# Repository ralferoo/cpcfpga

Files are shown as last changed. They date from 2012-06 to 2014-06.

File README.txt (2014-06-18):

PLEASE NOTE THAT THIS IS ONLY A PARTIAL REPOSITORY DUMP WHILE I TRY TO
SEPARATE PUBLIC AND PRIVATE PARTS...

-------------------------------------------------------------------------------

Contents
--------

This is the CPC FPGA project - a modern reimplementation of the Amstrad CPC
on an FPGA.

Whilst it's designed for use with the Amstrad CPC, the board could be
used for almost any 8-bit system. Alternatively, it could be used as a
cheap FPGA development board that includes a SCART socket, RAM, flash ROM,
PS/2 keyboard, twin joystick ports, tape input, etc...

The project is structured in these subdirectories:

bitstreams	Contains FPGA images that can be loaded from SD card
client		Contains Linux utilities to communicate with the board
datasheets	Miscellaneous datasheets (obtained publically, but are NOT
		part of this project)
docs		Various snippets of documentation I've written at various times
hardware/case	The case for revision 2 of CPC FPGA, for laser cutter use
hardware/eagle	The eagle schematic and circuit design for:
			homeboard30  (revision 1)
			homeboard99r (revision 2)
hardware/spice	Various spice analysis snippets
library/hdl	VHDL files that can be used in projects hosted on CPC FPGA
projects	Contains FPGA projects to be run on the CPC FPGA.
sidecar2	The firmware for the CPC FPGA suport chip
stuff		Old bits and bobs, to be deleted
Makefile	Used to build the system
README.txt	This file

-------------------------------------------------------------------------------

Building the CPC FPGA project
-----------------------------

The user part of CPC FPGA program can be built simply by running "make".

Other build targets:

all		Rebuild client and bitstreams
clean		Clean all build files, excluding final targets
bitstreams	Rebuild all the FPGA bitstream files

scan		Check to see if the CPC FPGA board is present
log		Keep an eye on the diagnostic log from the CPC FPGA board
dump		Dump the CPC FPGA image stored in the PROM
reload		Reload the CPC FPGA image stored in the PROM
xxx.load	Reload the CPC FPGA image for project xxx
xxx.program	Programs the CPC FPGA's PROM with the image for project xxx

sidecar2	Rebuild just the firmware
dfu		Install the firmware
reset		Resets the firmware

-------------------------------------------------------------------------------

LICENCES

The Atmega source code uses the LUFA library, licensed under the MIT library.
Please see licence/LUFA-License.txt for copyright information.

The schematic and board layout are currently licensed under the Creative
Commons Attribution-Share Alike 3.0.
Please see http://creativecommons.org/licenses/by-sa/3.0/ for more information.

If you make derivative works, you must license under a compatible licence
and include the following text:
Portions of this project are derived from CPC FPGA, (c) 2011-2013 Ranulf Doswell

Other than including the above attribution, you should rename the derivative
work so that it cannot be confused with the original CPC FPGA project, nor
can you refer to CPC FPGA in a manner that suggests the derivative work is
endorsed by CPC FGPA or used by CPC FPGA.

Any VHDL code is currently not open sourced unless explicitly mentioned.
The scope of the project is solely the hardware design and software for the
support chip.

If you need a commercial licence for the hardware portion of this project,
please contact licensing@ranulf.net for more information.

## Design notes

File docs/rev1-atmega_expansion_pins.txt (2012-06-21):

name		wire colour	raspberry pi pin

TDO_PROM	WHITE		GPIO 18 (IN) [seem to have broken 22]
TMS		GREY		GPIO 21
TCK		PURPLE		GPIO 17
TDI_FPGA	BLUE		GPIO 4

fpga	atmel	header left	header right	atmel

	PD7	EMER_BOOT	AT_RESET
		VCC		VCC
		GND		GND
	PB7	TDI_FPGA	TDO_EXP		PC6
	PB5	TCK		TDO_PROM	PB6
P87		HDR_SPARE	TMS		PB4
P86		HDR_SEL		SPI_SEL		PB0
P85		HDR_MISO	SPI_MISO	PB3
P84		HDR_SCLK	SPI_SCLK	PB1
P83		HDR_MOSI	SPI_MOSI	PB2

P99	PC4
P125	PC5
P124	PC7 / CLK0
P97	PD0
P96	PD1
P95	PD2	RXD
P93	PD3	TXD
P92	PD4
P90	PD5
89	PD6	RTS

oops, CTS should have been exposed to FPGA too

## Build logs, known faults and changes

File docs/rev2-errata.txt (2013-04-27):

Atmega PC7 is connected to TDI, would be more useful as CLKO

KEYCOL4..KEYCOL7 don't have pull-ups
JOY1_{FIRE,LEFT,RIGHT,SPARE} has double pull-ups

HDMI SCL,SDA,CEC don't have pull-ups
TFP410PAP SCL,SDA don't have pull-ups

PS/2 level conversion still has 2 different implementations, one works with
the squishy keyboards only, the other with the clicky keyboards only. WHY?

HDMI connector holes should be through plated so they can be soldered downm

Mini USB locator pins are too close

VCC and GND traces are only 0.4mm, next revision make these at least 0.6mm

TAPE_IN should have pull up resistors
arguably all the GPIO pins should too

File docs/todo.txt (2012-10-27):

Find out why some of my new flash chips don't work
Find out why some of the boards have bad RAM
Get SD card access working
Move joystick back onto 1 port, have more GPIO instead

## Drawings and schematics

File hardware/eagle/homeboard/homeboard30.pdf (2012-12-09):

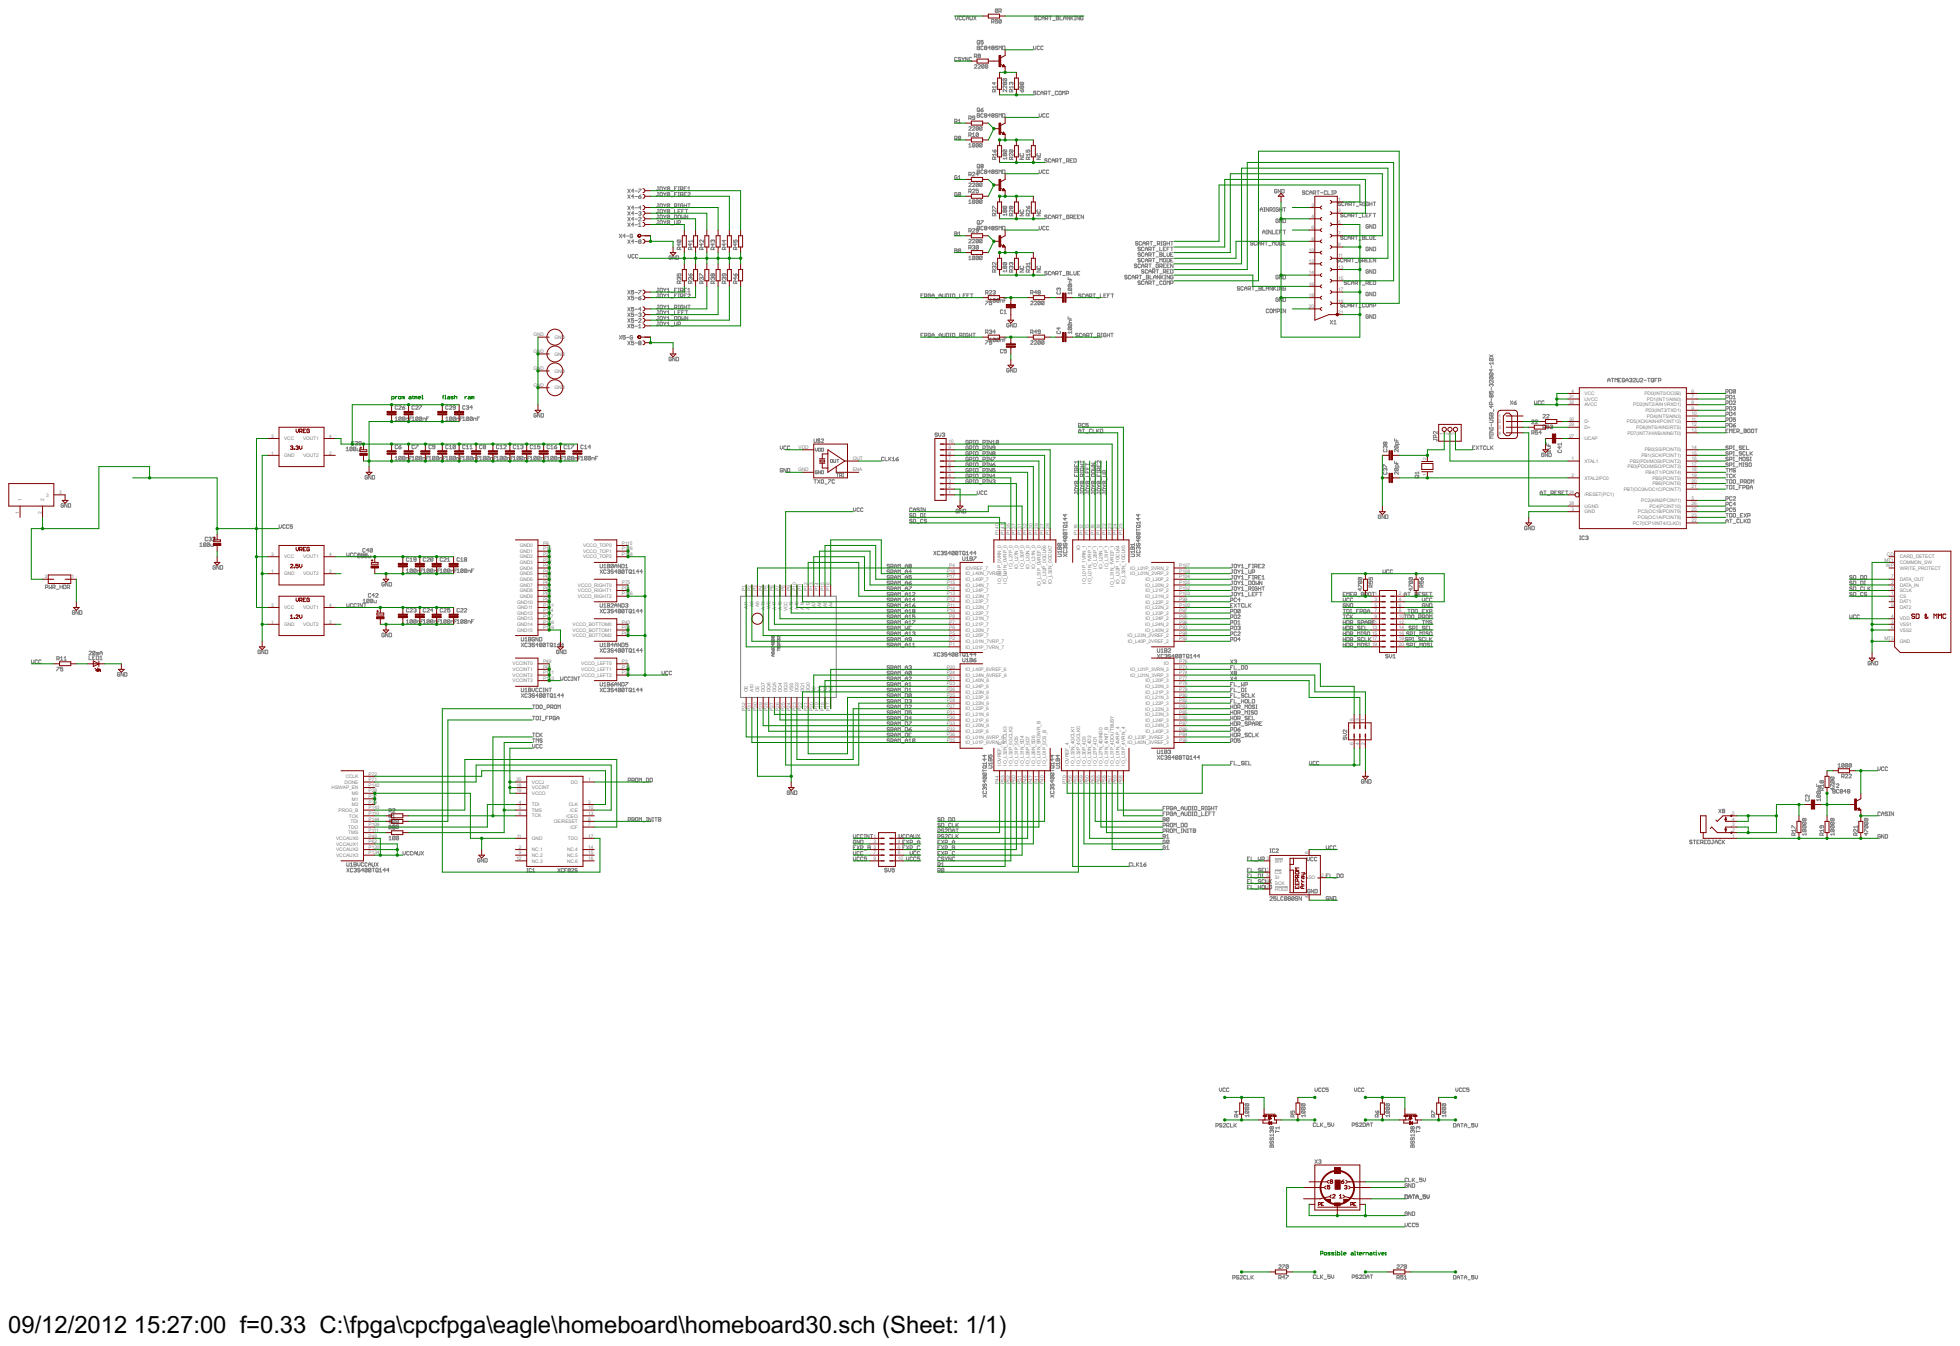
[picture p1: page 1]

09/12/2012 15:27:00 f=0.33 C:\fpga\cpcfpga\eagle\homeboard\homeboard30.sch (Sheet: 1/1)

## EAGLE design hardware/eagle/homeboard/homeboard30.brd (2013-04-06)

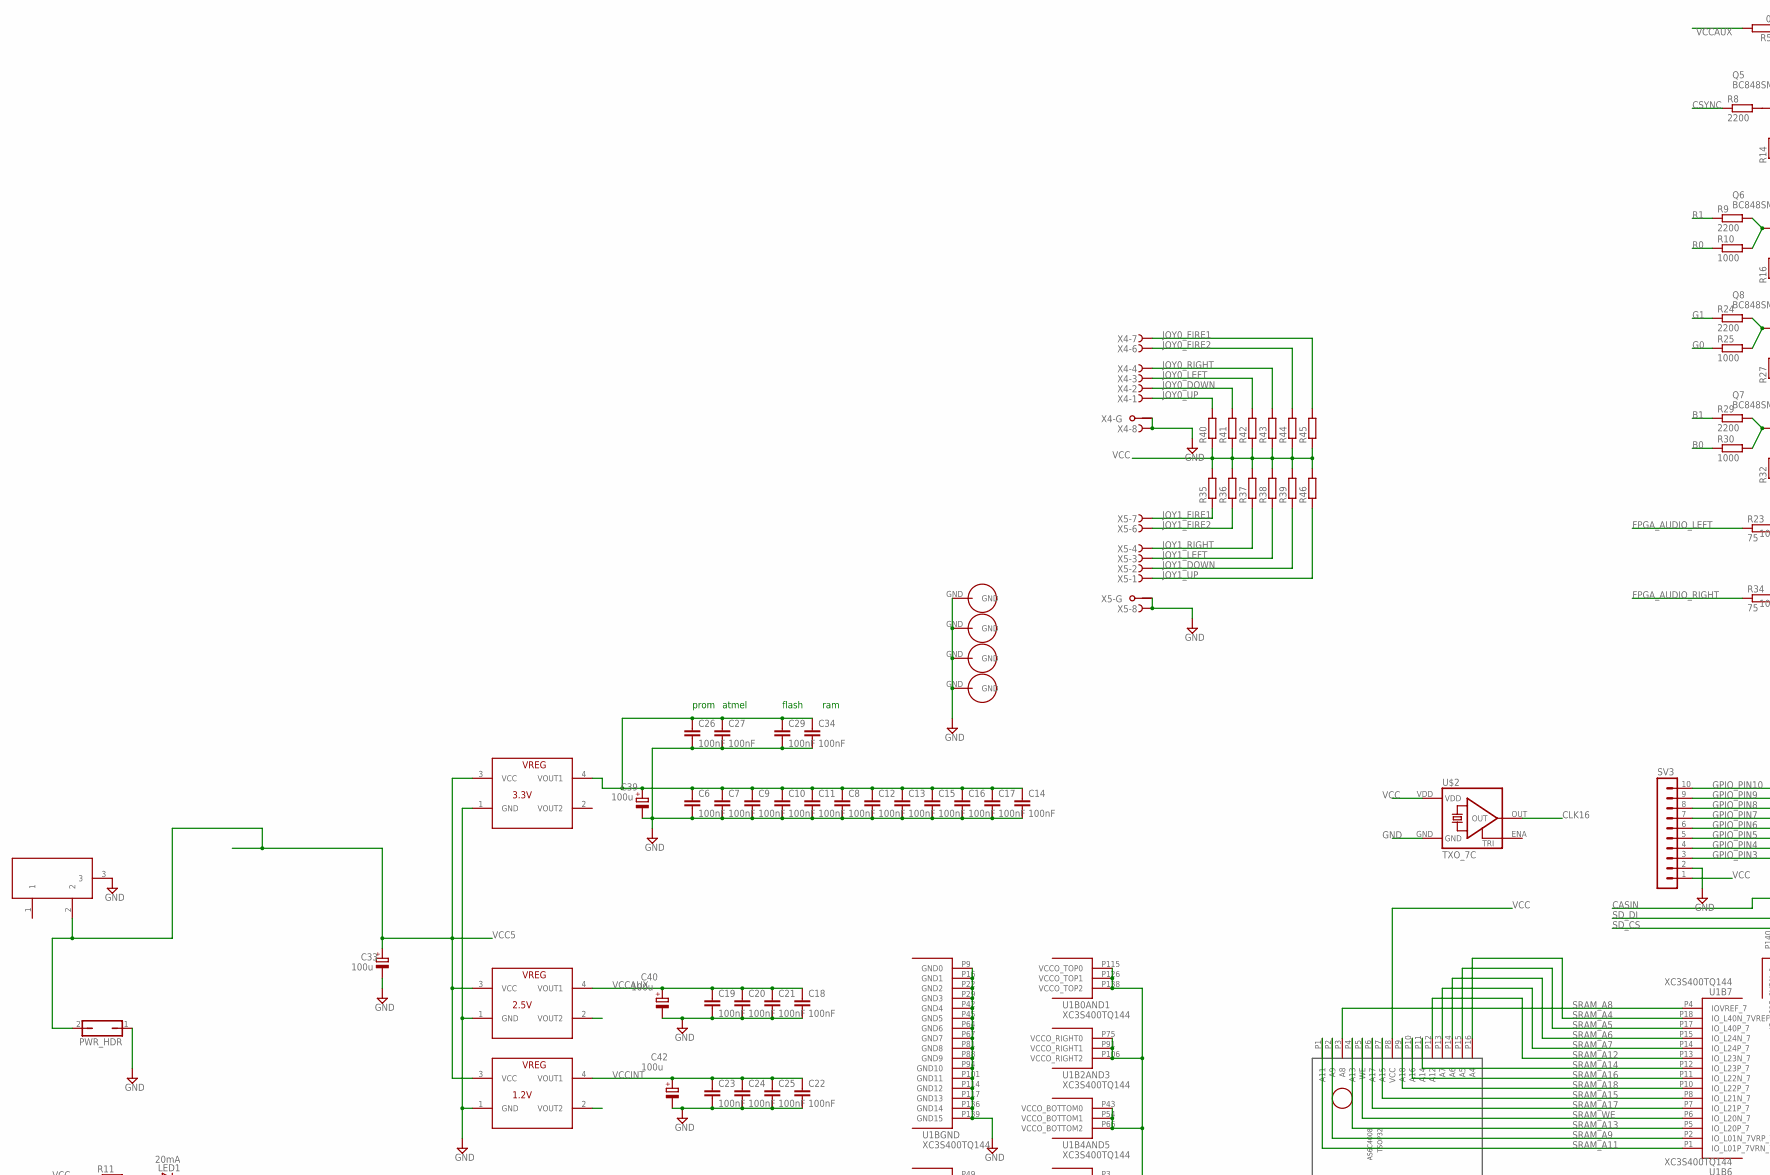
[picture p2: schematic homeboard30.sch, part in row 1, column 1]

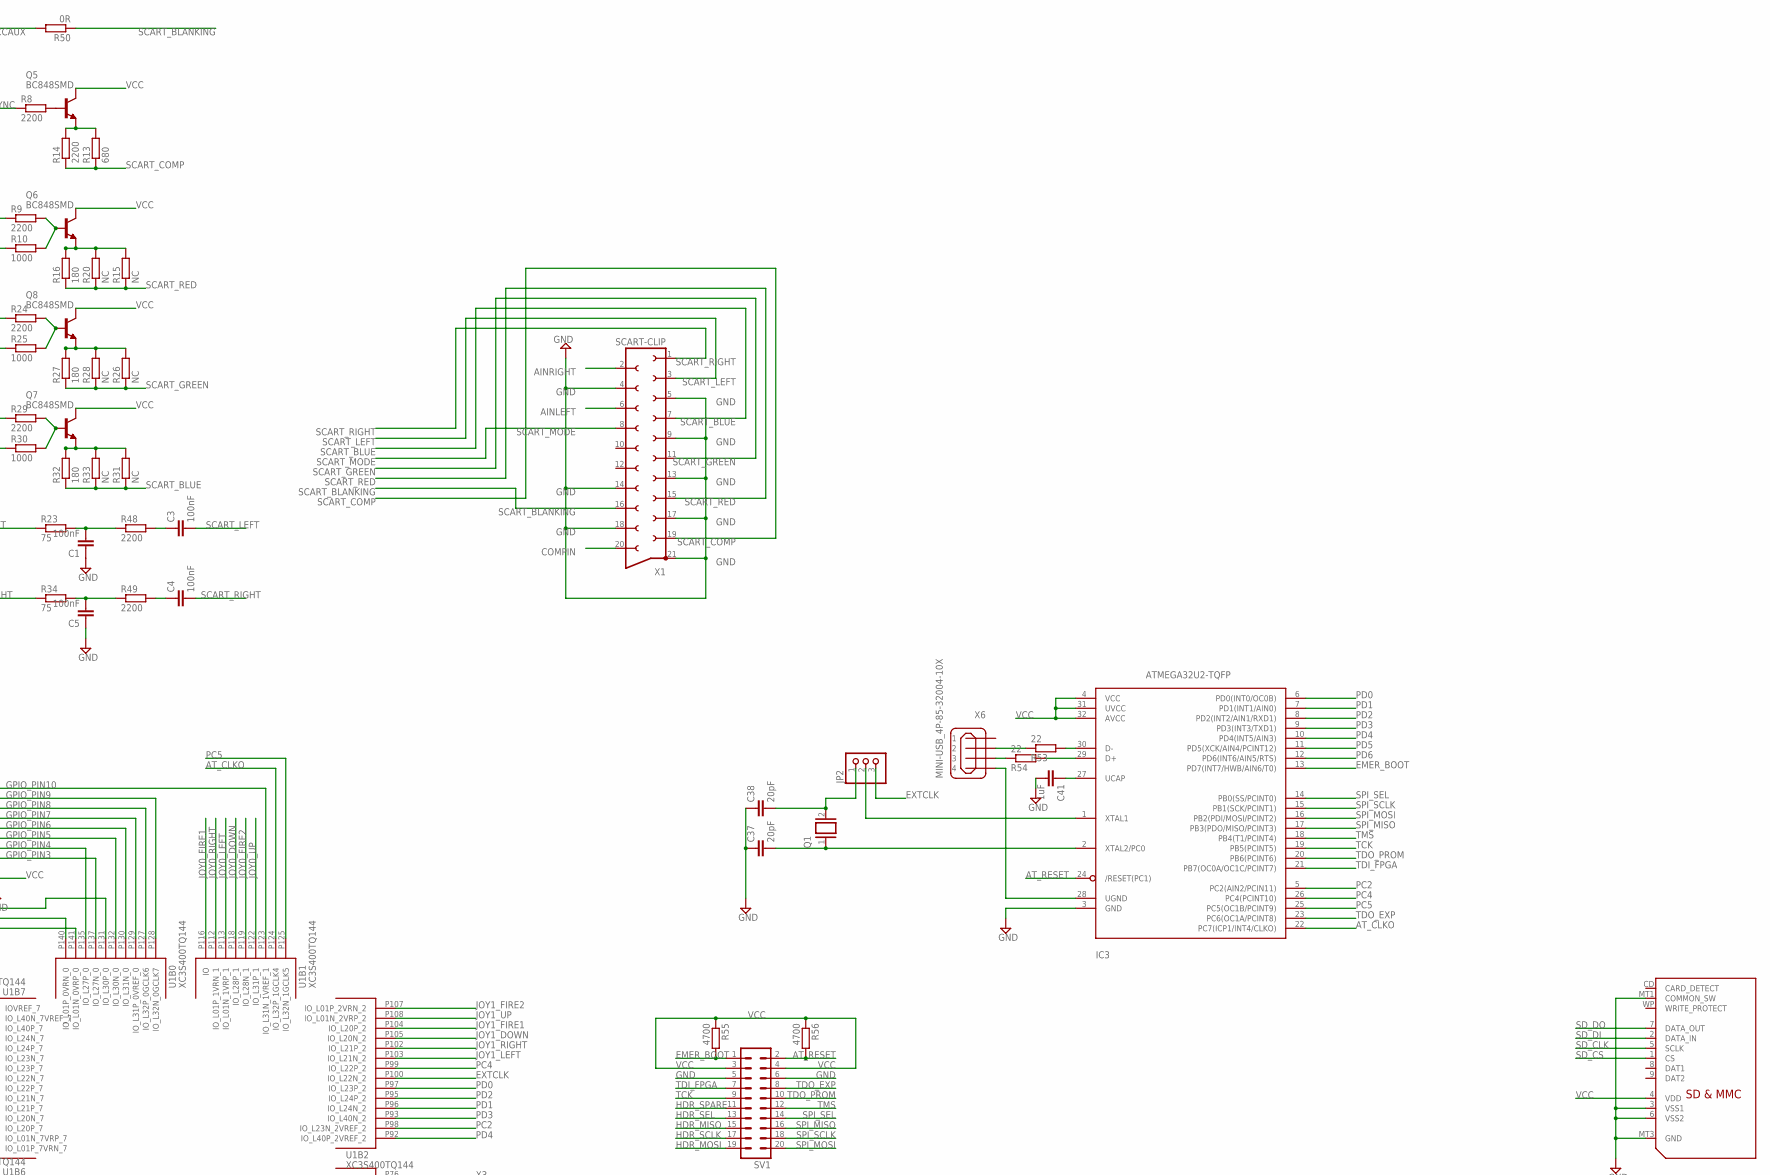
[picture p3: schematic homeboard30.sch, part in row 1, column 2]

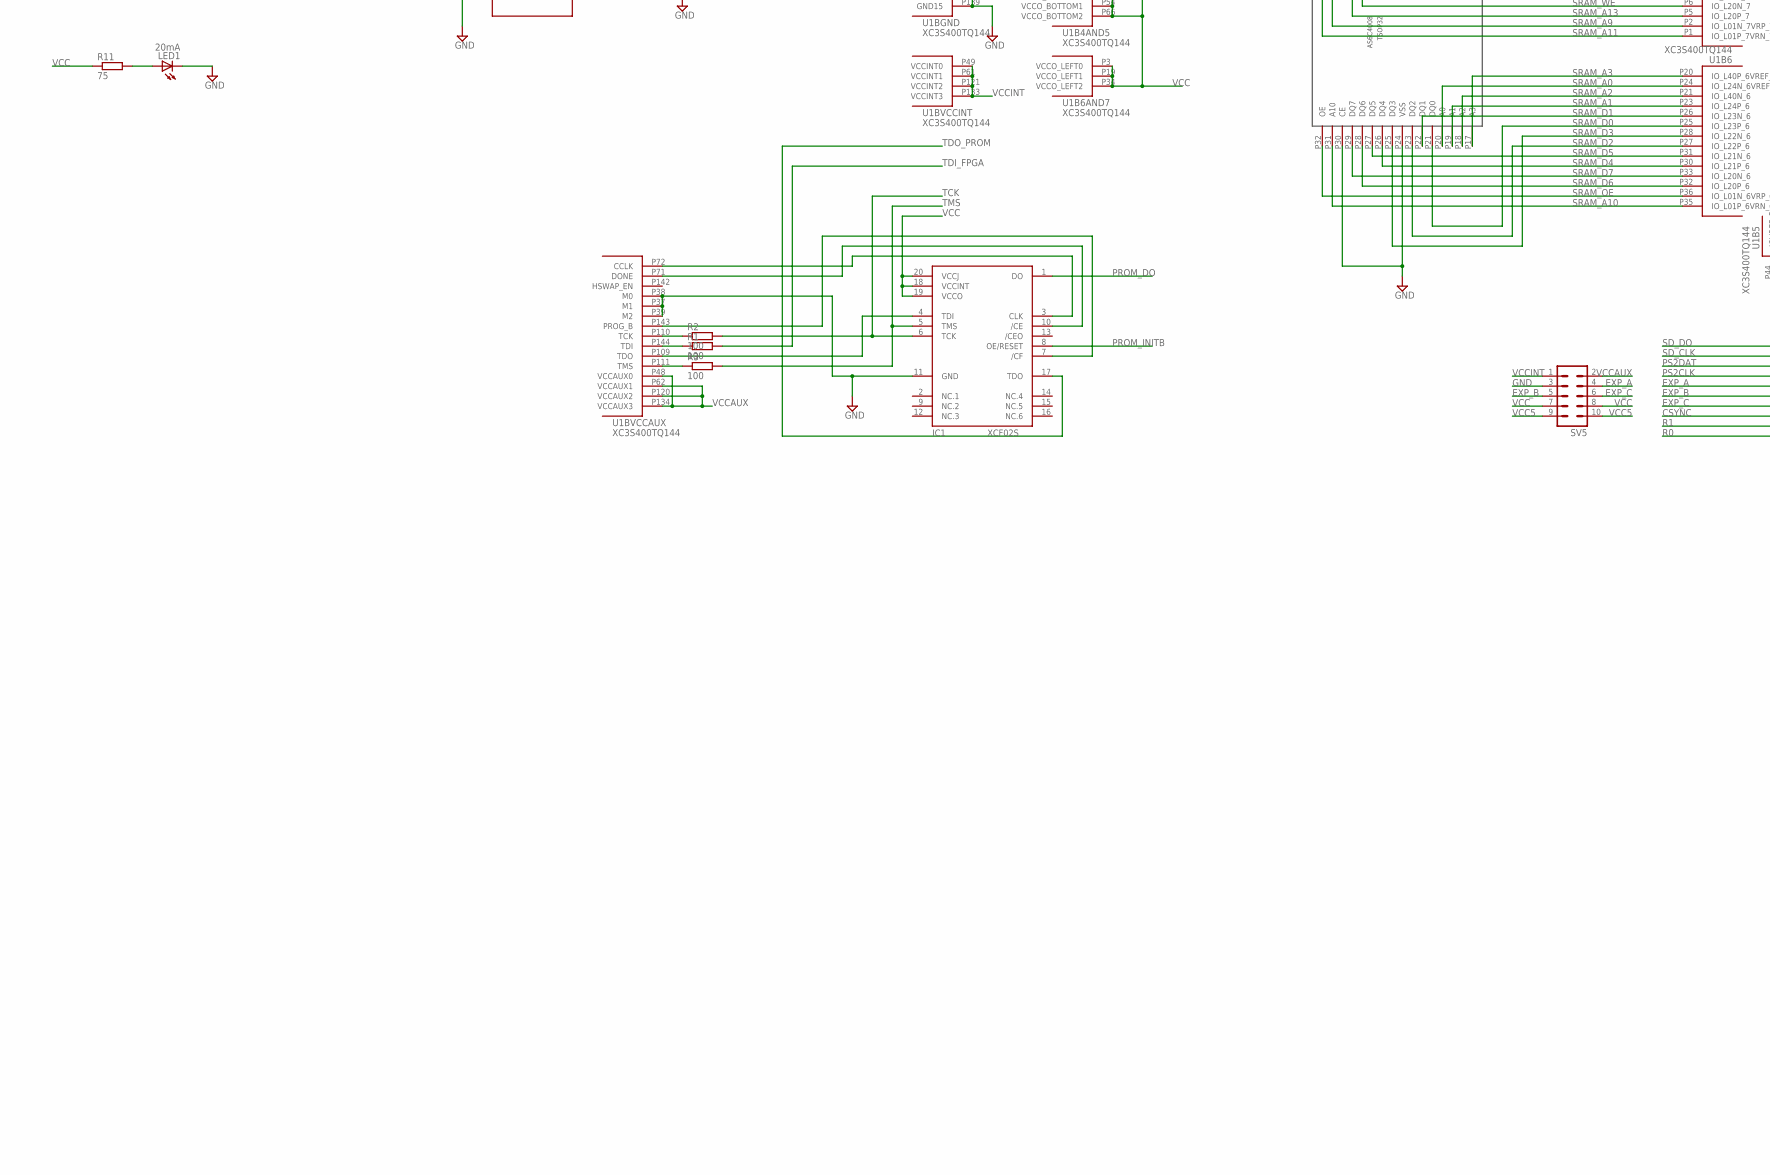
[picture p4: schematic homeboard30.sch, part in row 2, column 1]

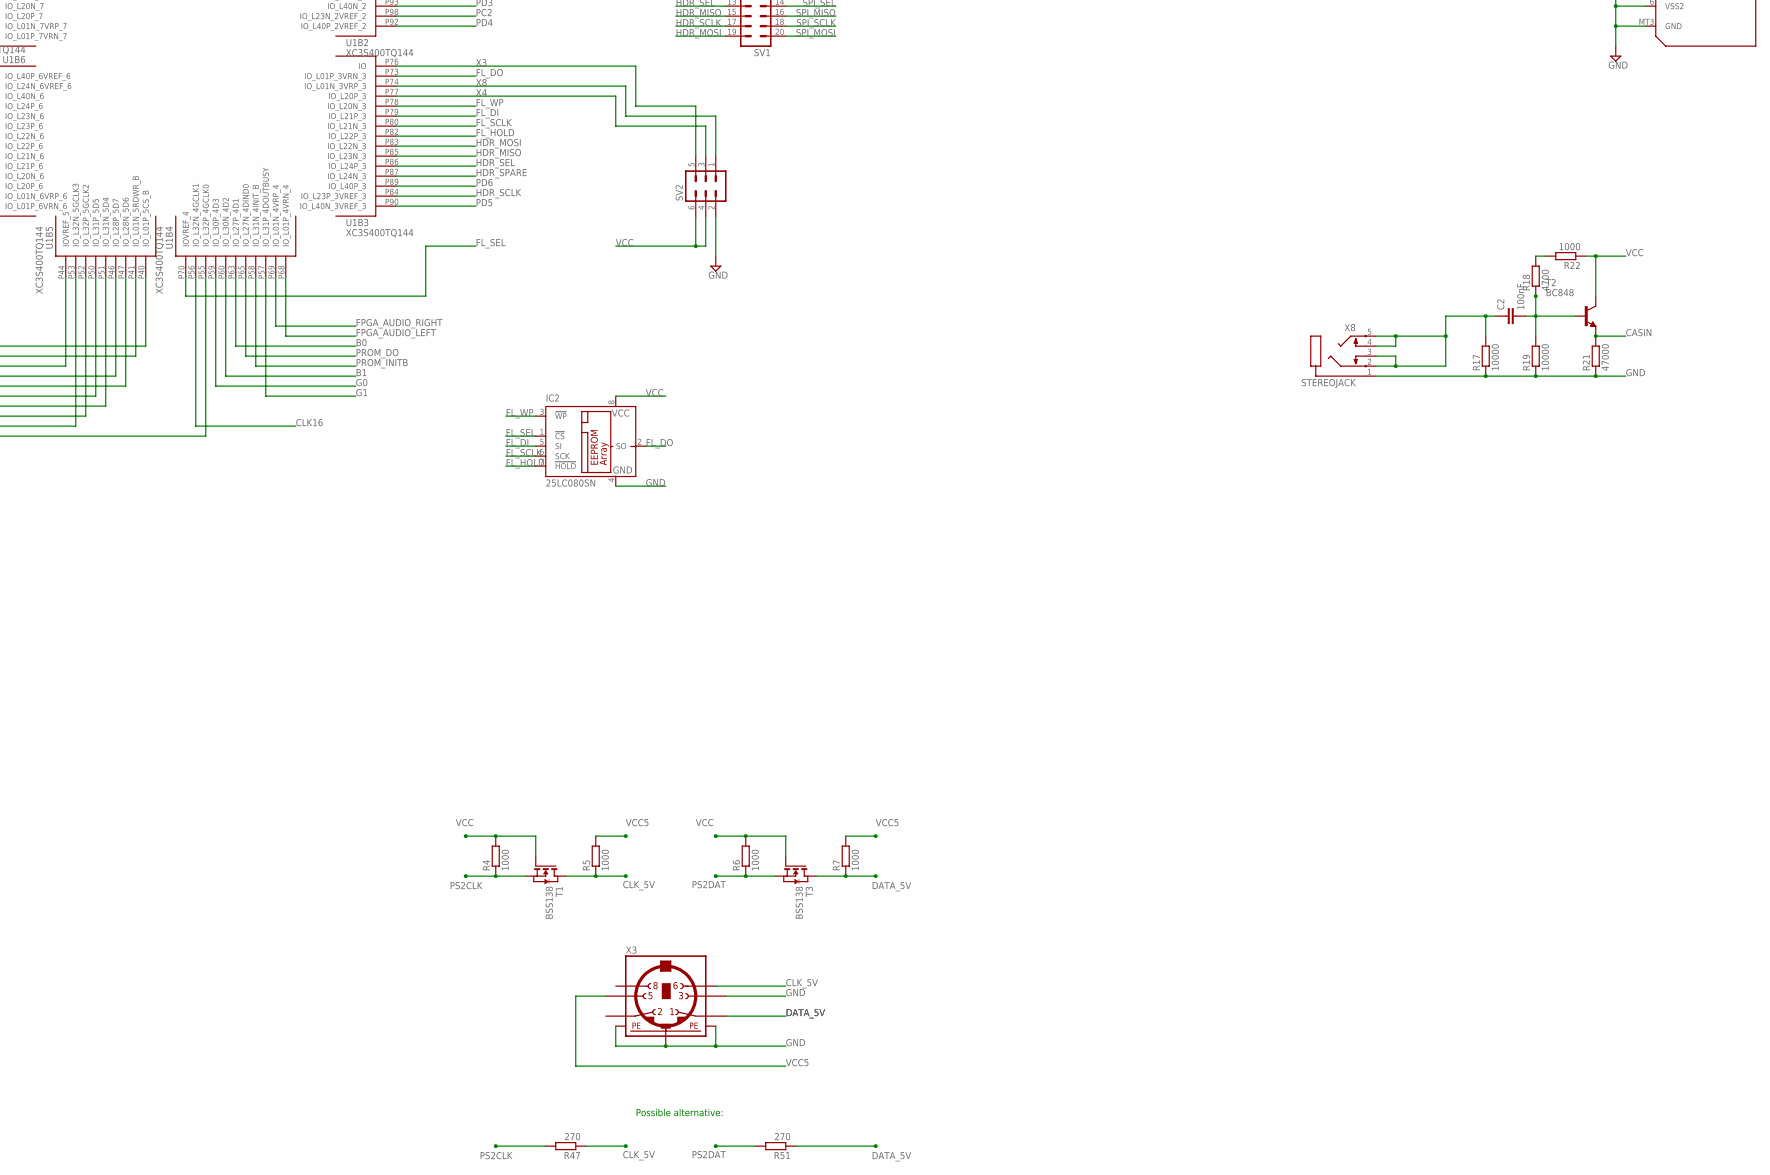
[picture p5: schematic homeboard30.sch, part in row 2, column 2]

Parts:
C1, C2, C3, C4, C5, C6, C7, C8, C9, C10, C11, C12, C13, C14, C15, C16, C17, C18, C19, C20, C21, C22, C23, C24, C25, C26, C27, C29, C34: 100nF; C0603
C33, C39, C40, C42: 100u; PANASONIC_D
C37, C38: 20pF; C0805
C41: 1uF; C0805
IC1: XCF02S; VO20
IC2: 25LC080SN; SO-08
IC3: ATMEGA32U2-TQFP; TQFP32-08
JP2: PINHD-1X3; 1X03
LED1: 20mA; CHIPLED_0805
PWR_HDR: JP1Q; JP1
Q1: XTAL/S; QS
Q5, Q6, Q7, Q8: BC848SMD; SOT23
R1, R2, R3: 100; R0805
R4, R5, R6, R7, R10, R22, R25, R30: 1000; R0805
R8, R9, R14, R24, R29: 2200; R0805
R11, R23, R34: 75; M0805
R13: 680; R0805
R15, R20, R26, R28, R31, R33: NC; R0805
R16, R27, R32: 180; R0805
R17, R19: 10000; R0805
R18, R55, R56: 4700; R0805
R21: 47000; R0805
R35, R36, R37, R38, R39, R40, R41, R42, R43, R44, R45, R46: R-EU_M0805; M0805
R47, R51: 270; R0805
R48, R49: 2200; M0805
R50: 0R; M0805
R53, R54: 22; R0805
REG1.2: 1.2V; SOT223
REG2.5: 2.5V; SOT223
REG3.3: 3.3V; SOT223
SV1: MA10-2
SV2: MA03-2
SV3: MA10-1
SV5: MA05-2
T1, T3: BSS138; SOT-23
T2: BC848; SOT23
U1: XC3S400TQ144; TQ144
U$1, U$7, U$8, U$9: GNDHOLE
U$2: TXO_7C; OSC_7C
U$3: SDMMCNOHOLE; SDCARD-NOHOLE
U$6: AS6C4008; TSOP32
X1: SCART-CLIP
X3: MINI_DIN_6; M_DIN6
X4, X5: F09HPS; F09HP
X6: MINI-USB_4P-85-32004-10X; 85-32004-10X
X7: DC21MMX; DC-21MM
X8: STEREOJACK; 20-0137

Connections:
1: X7.1
AINLEFT: X1.6
AINRIGHT: X1.2
AT_CLKO: IC3.22 (PC7(ICP1/INT4/CLKO)), U1.P124 (IO_L32P_1GCLK4)
AT_RESET: IC3.24 (/RESET(PC1)), R56.2, SV1.2
B0: R30.1, U1.P63 (IO_L27P_4D1)
B1: R29.1, U1.P60 (IO_L30N_4D2)
CASIN: R21.2, T2.2 (E), U1.P131 (IO_L30P_0)
CLK16: U1.P56 (IO_L32N_4GCLK1), U$2.OUT
CLK_5V: R5.1, R47.1, T1.1 (D), X3.6
COMPIN: X1.20
CSYNC: R8.1, U1.P52 (IO_L32P_5GCLK2)
DATA_5V: R7.1, R51.1, T3.1 (D), X3.1
EMER_BOOT: IC3.13 (PD7(INT7/HWB/AIN6/T0)), R55.2, SV1.1
EXP_A: SV5.4, U1.P47 (IO_L28N_5D6)
EXP_B: SV5.5, U1.P50 (IO_L31P_5D5)
EXP_C: SV5.6, U1.P51 (IO_L31N_5D4)
EXTCLK: JP2.3, U1.P100 (IO_L22N_2)
FL_DI: IC2.5 (SI), U1.P79 (IO_L21P_3)
FL_DO: IC2.2 (SO), U1.P73 (IO_L01P_3VRN_3)
FL_HOLD: IC2.7 (!HOLD), U1.P82 (IO_L22P_3)
FL_SCLK: IC2.6 (SCK), U1.P80 (IO_L21N_3)
FL_SEL: IC2.1 (!CS), U1.P70 (IOVREF_4)
FL_WP: IC2.3 (!WP), U1.P78 (IO_L20N_3)
FPGA_AUDIO_LEFT: R23.1, U1.P68 (IO_L01P_4VRN_4)
FPGA_AUDIO_RIGHT: R34.1, U1.P69 (IO_L01N_4VRP_4)
G0: R25.1, U1.P59 (IO_L30P_4D3)
G1: R24.1, U1.P57 (IO_L31P_4DOUTBUSY)
GND: C1.1, C5.1, C6.2, C7.2, C8.2, C9.2, C10.2, C11.2, C12.2, C13.2, C14.2, C15.2, C16.2, C17.2, C18.2, C19.2, C20.2, C21.2, C22.2, C23.2, C24.2, C25.2, C26.2, C27.2, C29.2, C33.-, C34.2, C37.1, C38.1, C39.-, C40.-, C41.2, C42.-, IC1.11 (GND), IC2.4 (GND), IC3.3 (GND), LED1.C, PWR_HDR.1, R17.1, R19.1, R21.1, REG1.2.1 (GND), REG2.5.1 (GND), REG3.3.1 (GND), SV1.5, SV1.6, SV2.2, SV3.2, SV5.3, U1.P9 (GND0), U1.P16 (GND1), U1.P22 (GND2), U1.P29 (GND3), U1.P37 (M1), U1.P38 (M0), U1.P39 (M2), U1.P42 (GND4), U1.P45 (GND5), U1.P64 (GND6), U1.P67 (GND7), U1.P81 (GND8), U1.P88 (GND9), U1.P94 (GND10), U1.P101 (GND11), U1.P114 (GND12), U1.P117 (GND13), U1.P136 (GND14), U1.P139 (GND15), U$1.GND, U$2.GND, U$3.3 (VSS1), U$3.6 (VSS2), U$3.MT1 (COMMON_SW), U$3.MT3 (GND), U$6.P24 (VSS), U$6.P30 (CE), U$7.GND, U$8.GND, U$9.GND, X1.4, X1.5, X1.9, X1.13, X1.14, X1.17, X1.18, X1.21, X3.3, X3.SH1 (PE1), X3.SH2 (PE2), X3.SH3 (PE3), X4.8 (F), X4.G1, X5.8 (F), X5.G1, X7.3, X8.1; also elsewhere on the board
GPIO_PIN3: SV3.3, U1.P137 (IO_L27N_0)
GPIO_PIN4: SV3.4, U1.P135 (IO_L27P_0)
GPIO_PIN5: SV3.5, U1.P132 (IO_L30N_0)
GPIO_PIN6: SV3.6, U1.P130 (IO_L31N_0)
GPIO_PIN7: SV3.7, U1.P129 (IO_L31P_0VREF_0)
GPIO_PIN8: SV3.8, U1.P127 (IO_L32P_0GCLK6)
GPIO_PIN9: SV3.9, U1.P128 (IO_L32N_0GCLK7)
GPIO_PIN10: SV3.10, U1.P123 (IO_L31N_1VREF_1)
HDR_MISO: SV1.15, U1.P85 (IO_L23N_3)
HDR_MOSI: SV1.19, U1.P83 (IO_L22N_3)
HDR_SCLK: SV1.17, U1.P84 (IO_L23P_3VREF_3)
HDR_SEL: SV1.13, U1.P86 (IO_L24P_3)
HDR_SPARE: SV1.11, U1.P87 (IO_L24N_3)
JOY0_DOWN: R41.2, U1.P118 (IO_L28P_1), X4.2 (F)
JOY0_FIRE1: R45.2, U1.P116 (IO), X4.7 (F)
JOY0_FIRE2: R44.2, U1.P119 (IO_L28N_1), X4.6 (F)
JOY0_LEFT: R42.2, U1.P113 (IO_L01N_1VRP_1), X4.3 (F)
JOY0_RIGHT: R43.2, U1.P112 (IO_L01P_1VRN_1), X4.4 (F)
JOY0_UP: R40.2, U1.P122 (IO_L31P_1), X4.1 (F)
JOY1_DOWN: R39.1, U1.P105 (IO_L20N_2), X5.2 (F)
JOY1_FIRE1: R35.1, U1.P104 (IO_L20P_2), X5.7 (F)
JOY1_FIRE2: R36.1, U1.P107 (IO_L01P_2VRN_2), X5.6 (F)
JOY1_LEFT: R38.1, U1.P103 (IO_L21N_2), X5.3 (F)
JOY1_RIGHT: R37.1, U1.P102 (IO_L21P_2), X5.4 (F)
JOY1_UP: R46.1, U1.P108 (IO_L01N_2VRP_2), X5.1 (F)
unnamed: IC3.1 (XTAL1), JP2.2
unnamed: C41.1, IC3.27 (UCAP)
unnamed: LED1.A, R11.2
unnamed: C37.2, IC3.2 (XTAL2/PC0), Q1.1
unnamed: C38.2, JP2.1, Q1.2
unnamed: IC1.3 (CLK), U1.P72 (CCLK)
unnamed: R53.1, X6.2
unnamed: IC1.10 (/CE), U1.P71 (DONE)
unnamed: R2.1, U1.P110 (TCK)
unnamed: IC1.7 (/CF), U1.P143 (PROG_B)
unnamed: R1.1, U1.P144 (TDI)
unnamed: R3.1, U1.P111 (TMS)
unnamed: IC3.29 (D+), R54.2
unnamed: C1.2, R23.2, R48.1
unnamed: C3.1, R48.2
unnamed: Q6.1 (B), R9.2, R10.2
unnamed: Q6.2 (E), R15.2, R16.2, R20.2
unnamed: Q8.1 (B), R24.2, R25.2
unnamed: Q8.2 (E), R26.2, R27.2, R28.2
unnamed: Q7.1 (B), R29.2, R30.2
unnamed: Q7.2 (E), R31.2, R32.2, R33.2
unnamed: Q5.2 (E), R13.2, R14.2
unnamed 77: C2.2, R18.1, R19.2, T2.1 (B); also elsewhere on the board
unnamed: C2.1, R17.2, X8.2, X8.3, X8.4, X8.5
unnamed: R18.2, R22.2
unnamed: Q5.1 (B), R8.2
unnamed: C4.1, R49.2
unnamed: C5.2, R34.2, R49.1
unnamed: R54.1, X6.3
unnamed: IC3.30 (D-), R53.2
unnamed: IC3.28 (UGND), X6.4
PC2: IC3.5 (PC2(AIN2/PCIN11)), U1.P98 (IO_L23N_2VREF_2)
PC4: IC3.26 (PC4(PCINT10)), U1.P99 (IO_L22P_2)
PC5: IC3.25 (PC5(OC1B/PCINT9)), U1.P125 (IO_L32N_1GCLK5)
PD0: IC3.6 (PD0(INT0/OC0B)), U1.P97 (IO_L23P_2)
PD1: IC3.7 (PD1(INT1/AIN0)), U1.P96 (IO_L24N_2)
PD2: IC3.8 (PD2(INT2/AIN1/RXD1)), U1.P95 (IO_L24P_2)
PD3: IC3.9 (PD3(INT3/TXD1)), U1.P93 (IO_L40N_2)
PD4: IC3.10 (PD4(INT5/AIN3)), U1.P92 (IO_L40P_2VREF_2)
PD5: IC3.11 (PD5(XCK/AIN4/PCINT12)), U1.P90 (IO_L40N_3VREF_3)
PD6: IC3.12 (PD6(INT6/AIN5/RTS)), U1.P89 (IO_L40P_3)
PROM_DO: IC1.1 (DO), U1.P65 (IO_L27N_4DIND0)
PROM_INITB: IC1.8 (OE/RESET), U1.P58 (IO_L31N_4INIT_B)
PS2CLK: R4.1, R47.2, T1.2 (S), U1.P46 (IO_L28P_5D7)
PS2DAT: R6.1, R51.2, T3.2 (S), U1.P44 (IOVREF_5)
R0: R10.1, U1.P55 (IO_L32P_4GCLK0)
R1: R9.1, U1.P53 (IO_L32N_5GCLK3)
SCART_BLANKING: R50.1, X1.16
SCART_BLUE: R31.1, R32.1, R33.1, X1.7
SCART_COMP: R13.1, R14.1, X1.19
SCART_GREEN: R26.1, R27.1, R28.1, X1.11
SCART_LEFT: C3.2, X1.3
SCART_MODE: X1.8
SCART_RED: R15.1, R16.1, R20.1, X1.15
SCART_RIGHT: C4.2, X1.1
SD_CLK: U1.P41 (IO_L01N_5RDWR_B), U$3.5 (SCLK)
SD_CS: U1.P141 (IO_L01N_0VRP_0), U$3.1 (CS)
SD_DI: U1.P140 (IO_L01P_0VRN_0), U$3.2 (DATA_IN)
SD_DO: U1.P40 (IO_L01P_5CS_B), U$3.7 (DATA_OUT)
SPI_MISO: IC3.17 (PB3(PDO/MISO/PCINT3)), SV1.16
SPI_MOSI: IC3.16 (PB2(PDI/MOSI/PCINT2)), SV1.20
SPI_SCLK: IC3.15 (PB1(SCK/PCINT1)), SV1.18
SPI_SEL: IC3.14 (PB0(SS/PCINT0)), SV1.14
SRAM_A0: U1.P24 (IO_L24N_6VREF_6), U$6.P20 (A0)
SRAM_A1: U1.P23 (IO_L24P_6), U$6.P19 (A1)
SRAM_A2: U1.P21 (IO_L40N_6), U$6.P18 (A2)
SRAM_A3: U1.P20 (IO_L40P_6VREF_6), U$6.P17 (A3)
SRAM_A4: U1.P18 (IO_L40N_7VREF_7), U$6.P16 (A4)
SRAM_A5: U1.P17 (IO_L40P_7), U$6.P15 (A5)
SRAM_A6: U1.P15 (IO_L24N_7), U$6.P14 (A6)
SRAM_A7: U1.P14 (IO_L24P_7), U$6.P13 (A7)
SRAM_A8: U1.P4 (IOVREF_7), U$6.P3 (A8)
SRAM_A9: U1.P2 (IO_L01N_7VRP_7), U$6.P2 (A9)
SRAM_A10: U1.P35 (IO_L01P_6VRN_6), U$6.P31 (A10)
SRAM_A11: U1.P1 (IO_L01P_7VRN_7), U$6.P1 (A11)
SRAM_A12: U1.P13 (IO_L23N_7), U$6.P12 (A12)
SRAM_A13: U1.P5 (IO_L20P_7), U$6.P4 (A13)
SRAM_A14: U1.P12 (IO_L23P_7), U$6.P11 (A14)
SRAM_A15: U1.P8 (IO_L21N_7), U$6.P7 (A15)
SRAM_A16: U1.P11 (IO_L22N_7), U$6.P10 (A16)
SRAM_A17: U1.P7 (IO_L21P_7), U$6.P6 (A17)
SRAM_A18: U1.P10 (IO_L22P_7), U$6.P9 (A18)
SRAM_D0: U1.P25 (IO_L23P_6), U$6.P21 (DQ0)
SRAM_D1: U1.P26 (IO_L23N_6), U$6.P22 (DQ1)
SRAM_D2: U1.P27 (IO_L22P_6), U$6.P23 (DQ2)
SRAM_D3: U1.P28 (IO_L22N_6), U$6.P25 (DQ3)
SRAM_D4: U1.P30 (IO_L21P_6), U$6.P26 (DQ4)
SRAM_D5: U1.P31 (IO_L21N_6), U$6.P27 (DQ5)
SRAM_D6: U1.P32 (IO_L20P_6), U$6.P28 (DQ6)
SRAM_D7: U1.P33 (IO_L20N_6), U$6.P29 (DQ7)
SRAM_OE: U1.P36 (IO_L01N_6VRP_6), U$6.P32 (OE)
SRAM_WE: U1.P6 (IO_L20N_7), U$6.P5 (WE)
TCK: IC1.6 (TCK), IC3.19 (PB5(PCINT5)), R2.2, SV1.9
TDI_FPGA: IC3.21 (PB7(OC0A/OC1C/PCINT7)), R1.2, SV1.7
TDO_EXP: IC3.23 (PC6(OC1A/PCINT8)), SV1.8
TDO_FPGA: IC1.4 (TDI), U1.P109 (TDO)
TDO_PROM: IC1.17 (TDO), IC3.20 (PB6(PCINT6)), SV1.10
TMS: IC1.5 (TMS), IC3.18 (PB4(T1/PCINT4)), R3.2, SV1.12
VCC: C6.1, C7.1, C8.1, C9.1, C10.1, C11.1, C12.1, C13.1, C14.1, C15.1, C16.1, C17.1, C26.1, C27.1, C29.1, C34.1, C39.+, IC1.18 (VCCINT), IC1.19 (VCCO), IC1.20 (VCCJ), IC2.8 (VCC), IC3.4 (VCC), IC3.31 (UVCC), IC3.32 (AVCC), Q5.3 (C), Q6.3 (C), Q7.3 (C), Q8.3 (C), R4.2, R6.2, R11.1, R22.1, R35.2, R36.2, R37.2, R38.2, R39.2, R40.1, R41.1, R42.1, R43.1, R44.1, R45.1, R46.2, R55.1, R56.1, REG3.3.4 (VOUT1), SV1.3, SV1.4, SV2.4, SV2.6, SV3.1, SV5.7, SV5.8, T1.3 (G), T2.3 (C), T3.3 (G), U1.P3 (VCCO_LEFT0), U1.P19 (VCCO_LEFT1), U1.P34 (VCCO_LEFT2), U1.P43 (VCCO_BOTTOM0), U1.P54 (VCCO_BOTTOM1), U1.P66 (VCCO_BOTTOM2), U1.P75 (VCCO_RIGHT0), U1.P91 (VCCO_RIGHT1), U1.P106 (VCCO_RIGHT2), U1.P115 (VCCO_TOP0), U1.P126 (VCCO_TOP1), U1.P138 (VCCO_TOP2), U$2.VDD, U$3.4 (VDD), U$6.P8 (VCC)
VCC5: C33.+, PWR_HDR.2, R5.2, R7.2, REG1.2.3 (VCC), REG2.5.3 (VCC), REG3.3.3 (VCC), SV5.9, SV5.10, X3.5, X7.2
VCCAUX: C18.1, C19.1, C20.1, C21.1, C40.+, R50.2, REG2.5.4 (VOUT1), SV5.2, U1.P48 (VCCAUX0), U1.P62 (VCCAUX1), U1.P120 (VCCAUX2), U1.P134 (VCCAUX3)
VCCINT: C22.1, C23.1, C24.1, C25.1, C42.+, REG1.2.4 (VOUT1), SV5.1, U1.P49 (VCCINT0), U1.P61 (VCCINT1), U1.P121 (VCCINT2), U1.P133 (VCCINT3)
X3: SV2.5, U1.P76 (IO)
X4: SV2.3, U1.P77 (IO_L20P_3)
X8: SV2.1, U1.P74 (IO_L01N_3VRP_3)

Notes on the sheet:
Possible alternative:
atmel
prom
flash
ram

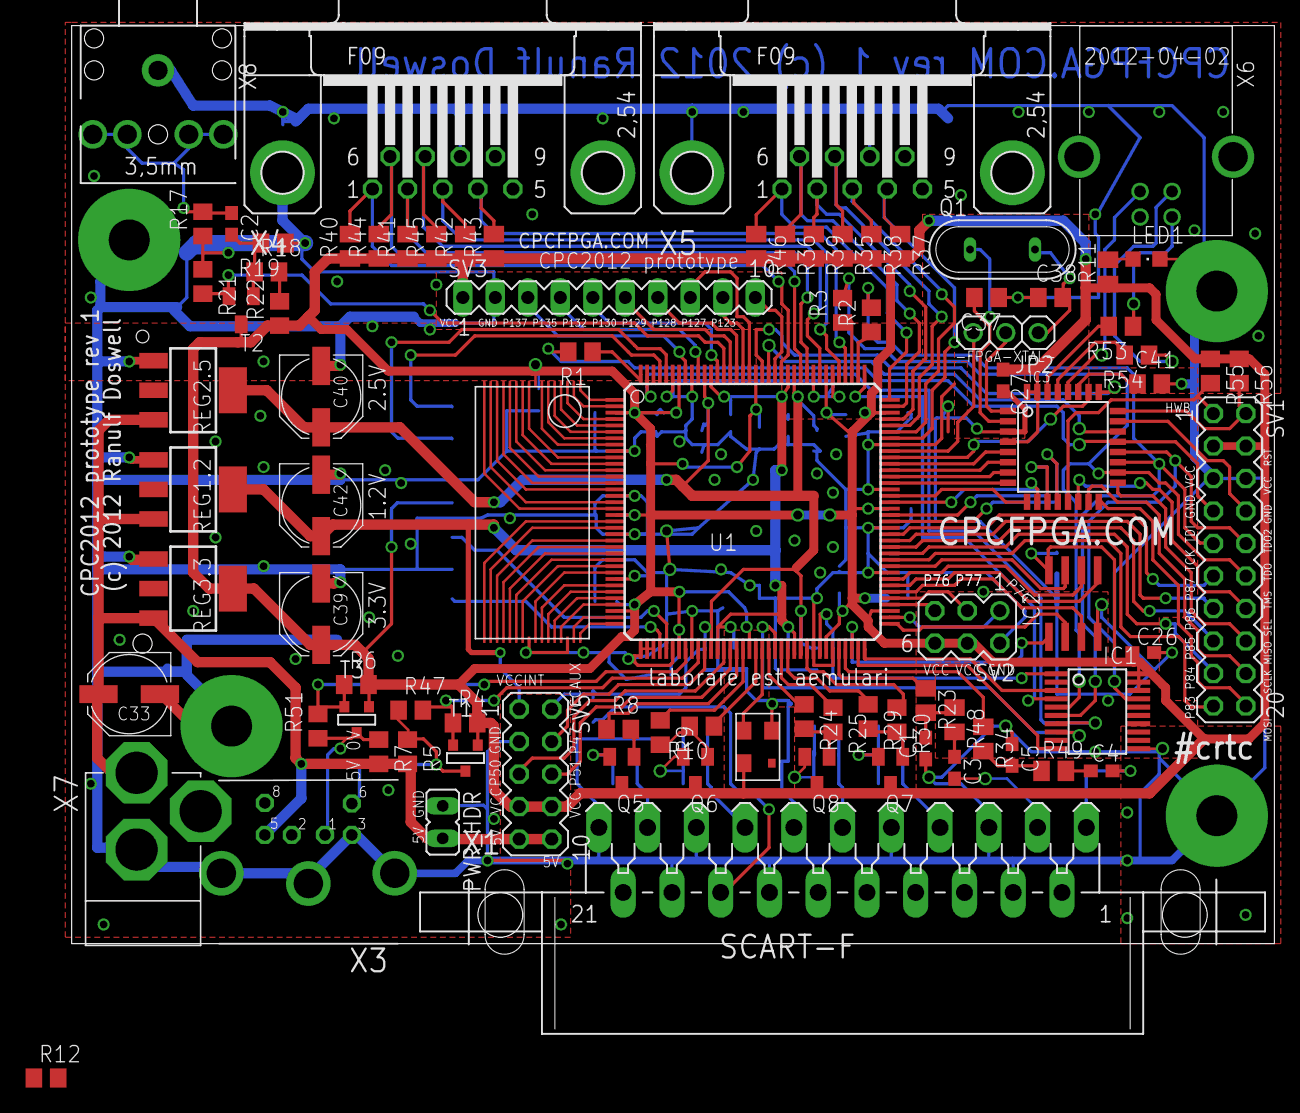
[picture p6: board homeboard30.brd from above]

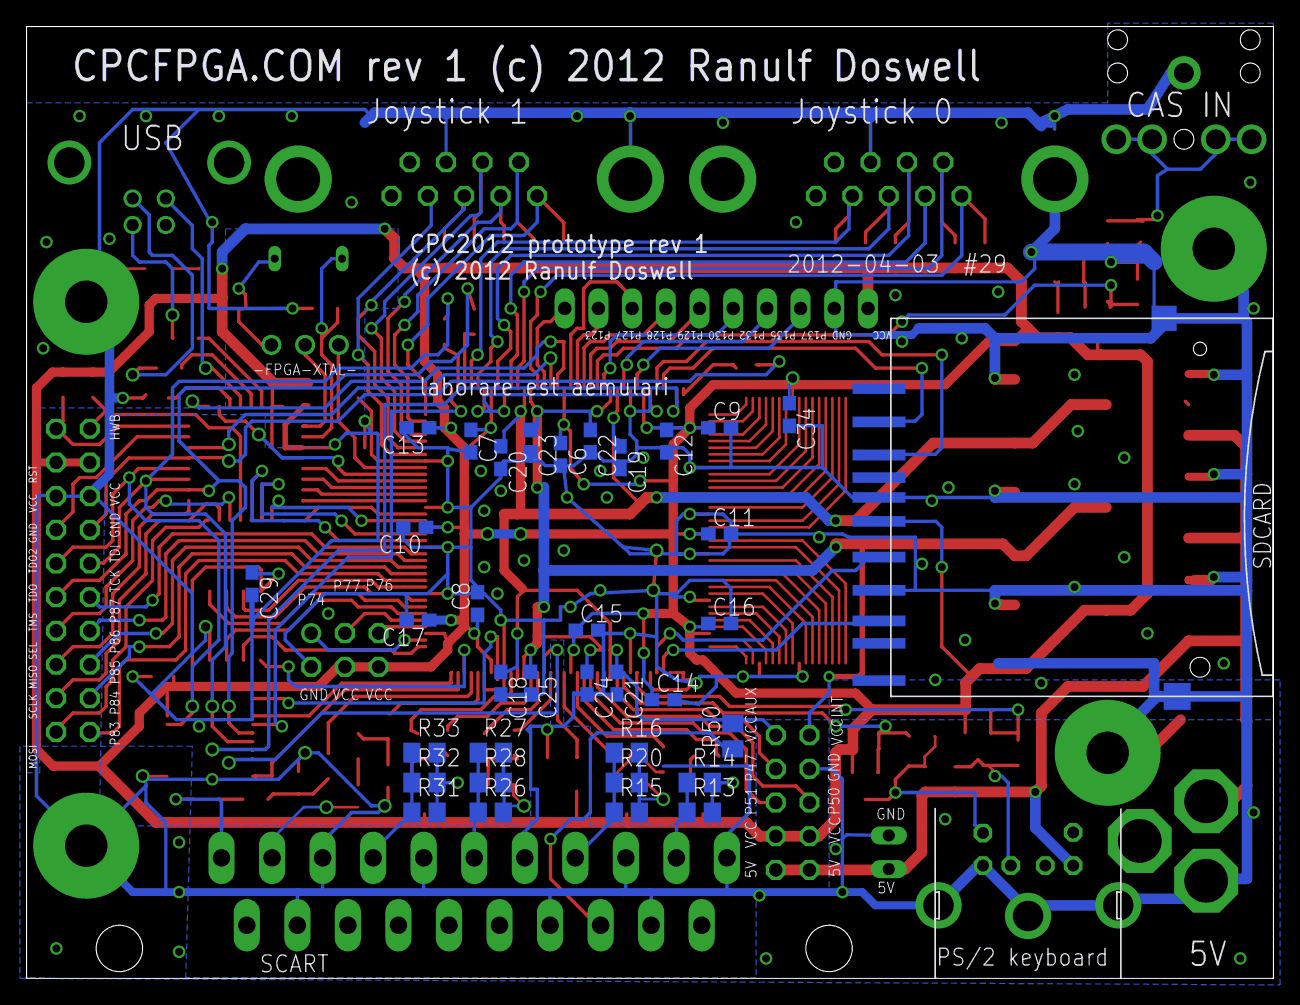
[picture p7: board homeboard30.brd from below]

Board: 2 copper layers, 94.0 x 71.8 mm, 127 parts (34 on the bottom side), 154 nets.

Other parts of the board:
R12: 47000; R0805

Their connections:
GND: R12.1; also elsewhere on the board
unnamed 77: R12.2; also elsewhere on the board

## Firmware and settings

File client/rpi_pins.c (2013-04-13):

#define DUMP_ALL_JTAG_TRAFFIC

#include <time.h>
#include <errno.h>

#include "gpio.h"

//#define GPIO_TMS 21
//#define GPIO_TCK 17
//#define GPIO_TDI 4
//#define GPIO_TDO 18 //22

#define GPIO_TMS 8
#define GPIO_TCK 25
#define GPIO_TDI 23
#define GPIO_TDO 24

#include <unistd.h>

#define BCM2708_PERI_BASE        0x20000000
#define GPIO_BASE                (BCM2708_PERI_BASE + 0x200000) /* GPIO controller */


#include <stdio.h>
#include <string.h>
#include <stdlib.h>
#include <dirent.h>
#include <fcntl.h>
#include <assert.h>
#include <sys/mman.h>
#include <sys/types.h>
#include <sys/stat.h>

#include <unistd.h>

#define PAGE_SIZE (4*1024)
#define BLOCK_SIZE (4*1024)

int  mem_fd;
char *gpio_mem, *gpio_map;
char *spi0_mem, *spi0_map;


// I/O access
volatile unsigned *gpio;


// GPIO setup macros. Always use INP_GPIO(x) before using OUT_GPIO(x) or SET_GPIO_ALT(x,y)
#define INP_GPIO(g) *(gpio+((g)/10)) &= ~(7<<(((g)%10)*3))
#define OUT_GPIO(g) *(gpio+((g)/10)) |=  (1<<(((g)%10)*3))
#define SET_GPIO_ALT(g,a) *(gpio+(((g)/10))) |= (((a)<=3?(a)+4:(a)==4?3:2)<<(((g)%10)*3))

#define GPIO_SET *(gpio+7)  // sets   bits which are 1 ignores bits which are 0
#define GPIO_CLR *(gpio+10) // clears bits which are 1 ignores bits which are 0
#define GPIO_LEV *(gpio+13) // gets levels of bits

void pinSetupIO();


#ifdef DUMP_ALL_JTAG_TRAFFIC
int dumper_fd = -1;
unsigned char dumper_buffer[10000];
int dumper_bufptr = 0;
int dumper_total = 0;
#endif

void TrafficDumpExit(void)
{
#ifdef DUMP_ALL_JTAG_TRAFFIC
	if (dumper_fd >= 0) {
//		printf("TrafficDumpExit flush\n");
		dumper_buffer[ dumper_bufptr++ ] = '\n';
		if (dumper_bufptr) {
			int wlen = write(dumper_fd, dumper_buffer, dumper_bufptr);
			if (dumper_bufptr != wlen)
				printf("Error flushing final jtag buffer wrote %d instead of %d bytes\n", wlen, dumper_bufptr);
		}
		close(dumper_fd);
		dumper_fd = -1;
		dumper_bufptr = 0;
	}
#endif
}

void TrafficDumpBit(int tms, int tdi, int tdo)
{
#ifdef DUMP_ALL_JTAG_TRAFFIC
	unsigned char out = tdi ?         '1' : '0';		//    1=TDI (from us to JTAG)
	if (tdo)		out |=    2;			//    2=TDO (from JTAG to us) 
	if (tms)		out |= 0x4;			// 0x8=TMS (JTAG transition)

	if ( (dumper_bufptr+4) > sizeof(dumper_buffer)) {
//		printf("TrafficDumpBit flush\n");
		if (dumper_fd >= 0) {
			int wlen = write(dumper_fd, dumper_buffer, dumper_bufptr);
			if (dumper_bufptr != wlen)
				printf("Error flushing jtag buffer wrote %d instead of %d bytes\n", wlen, dumper_bufptr);
		}
		dumper_bufptr = 0;
	}

	dumper_buffer[ dumper_bufptr++ ] = out;
	dumper_total++;
	if ((dumper_total&0x3f) == 0)
		dumper_buffer[ dumper_bufptr++ ] = '\n';
#endif
}

void TrafficDumpInit(void)
{
#ifdef DUMP_ALL_JTAG_TRAFFIC
	if (dumper_fd < 0) {
		char path_buffer[128];
		sprintf(path_buffer, "/jtaglogs/jtag-%ld.log", time(0) );
		dumper_fd = open(path_buffer, O_WRONLY | O_CREAT, 0777);
		dumper_bufptr = 0;
		dumper_total = 0;

		atexit(TrafficDumpExit);
	}
#endif
}


//
// Set up a memory regions to access GPIO
//
void pinSetupIO()
{

   /* open /dev/mem */
   if ((mem_fd = open("/dev/mem", O_RDWR|O_SYNC) ) < 0) {
      printf("can't open /dev/mem \n");
      exit (-1);
   }

   /* mmap GPIO */

   // Allocate MAP block
   if ((gpio_mem = malloc(BLOCK_SIZE + (PAGE_SIZE-1))) == NULL) {
      printf("allocation error \n");
      exit (-1);
   }

   // Make sure pointer is on 4K boundary
   if ((unsigned long)gpio_mem % PAGE_SIZE)
     gpio_mem += PAGE_SIZE - ((unsigned long)gpio_mem % PAGE_SIZE);

   // Now map it
   gpio_map = (unsigned char *)mmap(
      (caddr_t)gpio_mem,
      BLOCK_SIZE,
      PROT_READ|PROT_WRITE,
      MAP_SHARED|MAP_FIXED,
      mem_fd,
      GPIO_BASE
   );

   if ((long)gpio_map < 0) {
      printf("mmap error %d\n", (int)gpio_map);
      exit (-1);
   }

   // Always use volatile pointer!
   gpio = (volatile unsigned *)gpio_map;

#ifdef DUMP_ALL_JTAG_TRAFFIC
	TrafficDumpInit();
#endif


} // pinSetupIO

inline void pinSetDirectionInput(int i)
{
    INP_GPIO(i);
}

inline void pinSetDirectionOutput(int i)
{
    INP_GPIO(i); // must use INP_GPIO before we can use OUT_GPIO
    OUT_GPIO(i);
}

inline void pinOutput(int i, int v)
{
	if(v)
		GPIO_SET = 1<<i;
	else
		GPIO_CLR = 1<<i;
}

inline int pinInput(int i)
{
	return ( GPIO_LEV & (1<<i) ) ? 1 : 0;
}

///////////////////////////////////////////////////////////////////////////

void jtagInit(void)
{
	// Set up gpi pointer for direct register access
	pinSetupIO();

	// set pin directions
	pinOutput(GPIO_TMS,1);
	pinOutput(GPIO_TCK,0);
	pinSetDirectionOutput(GPIO_TMS);
	pinSetDirectionOutput(GPIO_TCK);
	pinSetDirectionOutput(GPIO_TDI);
	pinSetDirectionInput (GPIO_TDO);

	int i;
	for (i=0;i<20;i++)
		asm("nop;nop;nop;nop;nop;nop");	// 6/750 ms = 8ns
}

///////////////////////////////////////////////////////////////////////////
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

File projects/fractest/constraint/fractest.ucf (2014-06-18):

# SYSTEM
#

# this is temporary clock... broken the real one :(
#NET "CLK48"		LOC = "P53"	| IOSTANDARD = LVCMOS33;
NET "CLK_48"		LOC = "P128"	| IOSTANDARD = LVCMOS33;
NET "CLK_48" TNM_NET = "CLK_48";
TIMESPEC "TS_CLK48" = PERIOD "CLK_48" 20.833ns HIGH 50%;

###########################################################################

# Keyboard shift regs
#
NET "JOY_IN_DATA"	LOC = "P46"	| IOSTANDARD = LVCMOS33;
NET "JOY_KEY_LATCH"	LOC = "P40"	| IOSTANDARD = LVCMOS33;
NET "JOY_KEY_CLK"	LOC = "P44"	| IOSTANDARD = LVCMOS33;
NET "KEY_OUT_DATA"	LOC = "P41"	| IOSTANDARD = LVCMOS33;

###########################################################################

# SCART
#
NET "SCART_CSYNC"	LOC = "P112"	| IOSTANDARD = LVCMOS33;
NET "SCART_R[1]"	LOC = "P77"	| IOSTANDARD = LVCMOS33;
NET "SCART_R[0]"	LOC = "P73"	| IOSTANDARD = LVCMOS33;
NET "SCART_G[1]"	LOC = "P78"	| IOSTANDARD = LVCMOS33;
NET "SCART_G[0]"	LOC = "P74"	| IOSTANDARD = LVCMOS33;
NET "SCART_B[1]"	LOC = "P79"	| IOSTANDARD = LVCMOS33;
NET "SCART_B[0]"	LOC = "P76"	| IOSTANDARD = LVCMOS33;
NET "SCART_AUDIO_LEFT"	LOC = "P80"	| IOSTANDARD = LVCMOS33;
NET "SCART_AUDIO_RIGHT"	LOC = "P82"	| IOSTANDARD = LVCMOS33;

###########################################################################

# HDMI
#
#NET "HDMI_DATA[11]"	LOC = "P108"	| IOSTANDARD = LVCMOS33;
#NET "HDMI_DATA[10]"	LOC = "P107"	| IOSTANDARD = LVCMOS33;
#NET "HDMI_DATA[9]"	LOC = "P105"	| IOSTANDARD = LVCMOS33;
#NET "HDMI_DATA[8]"	LOC = "P104"	| IOSTANDARD = LVCMOS33;
#NET "HDMI_DATA[7]"	LOC = "P103"	| IOSTANDARD = LVCMOS33;
#NET "HDMI_DATA[6]"	LOC = "P102"	| IOSTANDARD = LVCMOS33;
#NET "HDMI_DATA[5]"	LOC = "P99"	| IOSTANDARD = LVCMOS33;
#NET "HDMI_DATA[4]"	LOC = "P98"	| IOSTANDARD = LVCMOS33;
#NET "HDMI_DATA[3]"	LOC = "P97"	| IOSTANDARD = LVCMOS33;
#NET "HDMI_DATA[2]"	LOC = "P96"	| IOSTANDARD = LVCMOS33;
#NET "HDMI_DATA[1]"	LOC = "P95"	| IOSTANDARD = LVCMOS33;
#NET "HDMI_DATA[0]"	LOC = "P93"	| IOSTANDARD = LVCMOS33;
#NET "HDMI_IDCK"		LOC = "P100"	| IOSTANDARD = LVCMOS33;

#NET "HDMI_TFP_SDA"	LOC = "P92"	| IOSTANDARD = LVCMOS33 | PULLUP;
#NET "HDMI_TFP_SCL"	LOC = "P90"	| IOSTANDARD = LVCMOS33 | PULLUP;

#NET "HDMI_DE"		LOC = "P89"	| IOSTANDARD = LVCMOS33;
#NET "HDMI_HSYNC"	LOC = "P87"	| IOSTANDARD = LVCMOS33;
#NET "HDMI_VSYNC"	LOC = "P86"	| IOSTANDARD = LVCMOS33;

#NET "HDMI_SDA"		LOC = "P84"	| IOSTANDARD = LVCMOS33 | PULLUP;
#NET "HDMI_SCL"		LOC = "P83"	| IOSTANDARD = LVCMOS33 | PULLUP;
#NET "HDMI_CEC"		LOC = "P85"	| IOSTANDARD = LVCMOS33 | PULLUP;

###########################################################################

# SRAM
#
NET "SRAM_ADDRESS[0]"	LOC = "P24"	| IOSTANDARD = LVCMOS33;
NET "SRAM_ADDRESS[1]"	LOC = "P23"	| IOSTANDARD = LVCMOS33;
NET "SRAM_ADDRESS[2]"	LOC = "P21"	| IOSTANDARD = LVCMOS33;
NET "SRAM_ADDRESS[3]"	LOC = "P20"	| IOSTANDARD = LVCMOS33;
NET "SRAM_ADDRESS[4]"	LOC = "P18"	| IOSTANDARD = LVCMOS33;
NET "SRAM_ADDRESS[5]"	LOC = "P17"	| IOSTANDARD = LVCMOS33;
NET "SRAM_ADDRESS[6]"	LOC = "P15"	| IOSTANDARD = LVCMOS33;
NET "SRAM_ADDRESS[7]"	LOC = "P14"	| IOSTANDARD = LVCMOS33;
NET "SRAM_ADDRESS[8]"	LOC = "P4"	| IOSTANDARD = LVCMOS33;
NET "SRAM_ADDRESS[9]"	LOC = "P2"	| IOSTANDARD = LVCMOS33;
NET "SRAM_ADDRESS[10]"	LOC = "P35"	| IOSTANDARD = LVCMOS33;
NET "SRAM_ADDRESS[11]"	LOC = "P1"	| IOSTANDARD = LVCMOS33;
NET "SRAM_ADDRESS[12]"	LOC = "P13"	| IOSTANDARD = LVCMOS33;
NET "SRAM_ADDRESS[13]"	LOC = "P5"	| IOSTANDARD = LVCMOS33;
NET "SRAM_ADDRESS[14]"	LOC = "P12"	| IOSTANDARD = LVCMOS33;
NET "SRAM_ADDRESS[15]"	LOC = "P8"	| IOSTANDARD = LVCMOS33;
NET "SRAM_ADDRESS[16]"	LOC = "P11"	| IOSTANDARD = LVCMOS33;
NET "SRAM_ADDRESS[17]"	LOC = "P7"	| IOSTANDARD = LVCMOS33;
NET "SRAM_ADDRESS[18]"	LOC = "P10"	| IOSTANDARD = LVCMOS33;
NET "SRAM_DATA[0]"	LOC = "P25"	| IOSTANDARD = LVCMOS33;
NET "SRAM_DATA[1]"	LOC = "P26"	| IOSTANDARD = LVCMOS33;
NET "SRAM_DATA[2]"	LOC = "P27"	| IOSTANDARD = LVCMOS33;
NET "SRAM_DATA[3]"	LOC = "P28"	| IOSTANDARD = LVCMOS33;
NET "SRAM_DATA[4]"	LOC = "P30"	| IOSTANDARD = LVCMOS33;
NET "SRAM_DATA[5]"	LOC = "P31"	| IOSTANDARD = LVCMOS33;
NET "SRAM_DATA[6]"	LOC = "P32"	| IOSTANDARD = LVCMOS33;
NET "SRAM_DATA[7]"	LOC = "P33"	| IOSTANDARD = LVCMOS33;
NET "SRAM_OE"		LOC = "P36"	| IOSTANDARD = LVCMOS33;
NET "SRAM_WE"		LOC = "P6"	| IOSTANDARD = LVCMOS33;

###########################################################################

# TAPE / KEYBOARD / JOYSTICK
#
#NET "CASIN"		LOC = "P131"	| IOSTANDARD = LVCMOS33;

#NET "PS2_CLOCK"		LOC = "P118"	| IOSTANDARD = LVCMOS33;
#NET "PS2_DATA"		LOC = "P113"	| IOSTANDARD = LVCMOS33;

###########################################################################

# FLASH
#
#NET "FL_DO"	LOC = "P63"	| IOSTANDARD = LVCMOS33 | SLEW = FAST;
#NET "FL_SEL"	LOC = "P68"	| IOSTANDARD = LVCMOS33 | SLEW = FAST;
#NET "FL_DI"	LOC = "P69"	| IOSTANDARD = LVCMOS33 | SLEW = FAST;
#NET "FL_SCLK"	LOC = "P70"	| IOSTANDARD = LVCMOS33 | SLEW = FAST;

###########################################################################

# EXPANSION
#

#NET "GPIO0"	LOC = "P60"	| IOSTANDARD = LVCMOS33;
#NET "GPIO1"	LOC = "P59"	| IOSTANDARD = LVCMOS33;
#NET "GPIO2"	LOC = "P57"	| IOSTANDARD = LVCMOS33;
#NET "GPIO3"	LOC = "P56"	| IOSTANDARD = LVCMOS33;
#NET "GPIO4"	LOC = "P55"	| IOSTANDARD = LVCMOS33;
#NET "GPIO5"	LOC = "P53"	| IOSTANDARD = LVCMOS33;
#NET "GPIO6"	LOC = "P52"	| IOSTANDARD = LVCMOS33;
#NET "GPIO7"	LOC = "P51"	| IOSTANDARD = LVCMOS33;
#NET "GPIO8"	LOC = "P50"	| IOSTANDARD = LVCMOS33;
#NET "GPIO9"	LOC = "P47"	| IOSTANDARD = LVCMOS33;

#NET "PC2"		LOC = "P98"	| IOSTANDARD = LVCMOS33;
#NET "PC4"		LOC = "P99"	| IOSTANDARD = LVCMOS33;
#NET "PC5"		LOC = "P125"	| IOSTANDARD = LVCMOS33;

#NET "AVR_SS"		LOC = "P132"	| IOSTANDARD = LVCMOS33 | PULLUP;
#NET "AVR_SCLK"		LOC = "P130"	| IOSTANDARD = LVCMOS33 | PULLUP;
#NET "AVR_MOSI"		LOC = "P129"	| IOSTANDARD = LVCMOS33 | PULLUP;
#NET "AVR_MISO"		LOC = "P127"	| IOSTANDARD = LVCMOS33 | PULLUP;
#NET "PB4"		LOC = "P125"	| IOSTANDARD = LVCMOS33;
#NET "PB5"		LOC = "P124"	| IOSTANDARD = LVCMOS33;
#NET "PB6"		LOC = "P123"	| IOSTANDARD = LVCMOS33;
#NET "PB7"		LOC = "P122"	| IOSTANDARD = LVCMOS33;

#NET "SD_CLK"		LOC = "P140"	| IOSTANDARD = LVCMOS33 | PULLUP;
#NET "SD_CS"		LOC = "P135"	| IOSTANDARD = LVCMOS33 | PULLUP;
#NET "SD_DI"		LOC = "P137"	| IOSTANDARD = LVCMOS33 | PULLUP;
#NET "SD_DO"		LOC = "P141"	| IOSTANDARD = LVCMOS33 | PULLUP;
##NET "SD_SPARE"		LOC = "P131"	| IOSTANDARD = LVCMOS33;

#NET "TXD"		LOC = "P116"	| IOSTANDARD = LVCMOS33;
#NET "RXD"		LOC = "P119"	| IOSTANDARD = LVCMOS33;

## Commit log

2012-06-21 revision 1 board schematics, spice models and header description
    [homeboard30.sch]
2012-06-21 JTAG programmer via GPIO pins on raspberry pi
2012-06-22 added UCF constraint files to document FPGA pin usage
2013-04-06 added board layout file
    [homeboard30.brd]
2013-04-13 updated atmega with new USB VID/PID, updated pins to revision 2 board
2013-04-13 notes for rev2 board
2013-04-13 updated libusb to reflect new USB VID/PID
2013-04-21 pull resistors in constraints during boundary scan
2013-05-02 added current state of sdtest - avr and libusb side
2014-06-18 tidying up
    [homeboard30.brd, homeboard30.sch]

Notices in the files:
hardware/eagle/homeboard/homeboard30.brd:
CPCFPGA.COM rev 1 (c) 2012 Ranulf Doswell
